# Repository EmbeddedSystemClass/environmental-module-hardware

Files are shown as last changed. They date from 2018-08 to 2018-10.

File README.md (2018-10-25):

irnas_logo
# enviromental-module-hardware

Enviromental module is adafruit feather compatible pinout hardware module. It has Murata Lora module on board, which is used for loraWan communication. It integrates a MCP25625 CAN controller with integrated Tranciver.

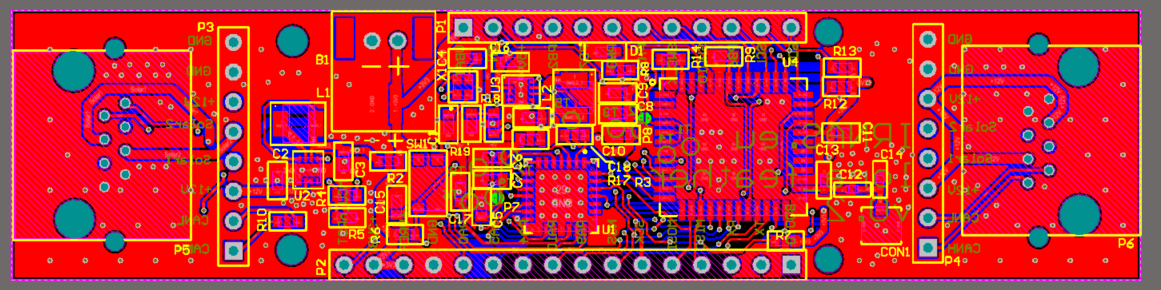
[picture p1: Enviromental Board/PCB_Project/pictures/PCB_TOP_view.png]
enviromental-PCB

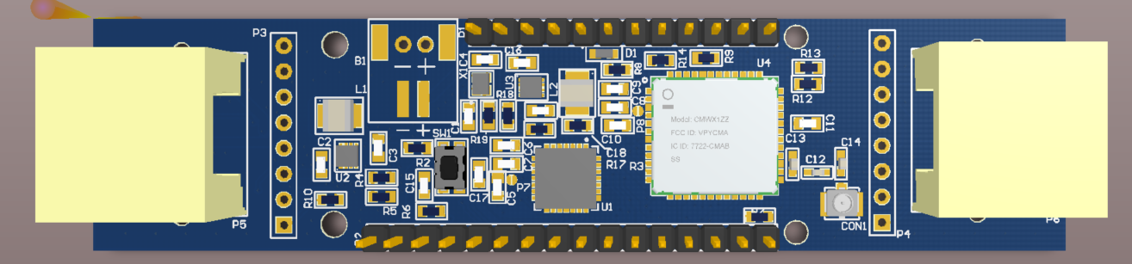
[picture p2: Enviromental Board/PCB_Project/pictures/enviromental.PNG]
enviromental-3D


## Connectors pinout 

* PIN1 - +3V3/VBAT
* PIN2 - EN
* PIN3 - +5V
* PIN4 - PB2
* PIN5 - PB7
* PIN6 - PH0
* PIN7 - PH1
* PIN8 - SWCLK
* PIN9 - SWDIO
* PIN10 - PB6
* PIN11 - SCL
* PIN12 - SDA
* PIN13 - BOOT0
* PIN14 - TX
* PIN15 - RX
* PIN16 - MISO
* PIN17 - MOSI
* PIN18 - SCK
* PIN19 - NSS
* PIN20 - PA9
* PIN21 - PA10
* PIN22 - PA4
* PIN23 - PA5
* PIN24 - PA0
* PIN25 - GND
* PIN26 - +VREF
* PIN27 - +3V3
* PIN28 - MCU_nRST

Besides this pins, on board there are also ethernet connectors, modified for special use case scenario. It provides the board with +12V input voltage, Can bus, and Solar connection.

block-diagram-envinromental
#### License

All our projects are as usefully open-source as possible.

Hardware including documentation is licensed under [CERN OHL v.1.2. license](http://www.ohwr.org/licenses/cern-ohl/v1.2)

Firmware and software originating from the project is licensed under [GNU GENERAL PUBLIC LICENSE v3](http://www.gnu.org/licenses/gpl-3.0.en.html).

Open data generated by our projects is licensed under [CC0](https://creativecommons.org/publicdomain/zero/1.0/legalcode).

All our websites and additional documentation are licensed under [Creative Commons Attribution-ShareAlike 4 .0 Unported License](https://creativecommons.org/licenses/by-sa/4.0/legalcode).

What this means is that you can use hardware, firmware, software and documentation without paying a royalty and knowing that you'll be able to use your version forever. You are also free to make changes but if you share these changes then you have to do so on the same conditions that you enjoy.

Koruza, GoodEnoughCNC and IRNAS are all names and marks of Institut IRNAS Rače. 
You may use these names and terms only to attribute the appropriate entity as required by the Open Licences referred to above. You may not use them in any other way and in particular you may not use them to imply endorsement or authorization of any hardware that you design, make or sell.

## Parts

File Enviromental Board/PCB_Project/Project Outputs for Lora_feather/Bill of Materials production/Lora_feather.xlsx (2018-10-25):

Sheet: Part List Report
 | Component list |  |  | <Parameter ProjectTitle not found>
 | Source Data From: | Lora_feather.PcbDoc |  |  | Contact:
 | Project: | Lora_feather.PrjPcb
 | Variant: | None |  |  |  |  |  |  | IRNAS
 | Report Date: | 09/10/2018 | 3:30:58 PM |  |  |  |  |  | www.irnas.eu
 | Print Date: | 2018-09-11 | 10:51:26
# | Manufacturer Part Number 1 | Manufacturer 1 | Description | Footprint | Designator | Quantity | Supplier 1 | Supplier Part Number 1 | Supplier Order Qty 1 | Supplier Stock 1 | Supplier Unit Price 1 | Supplier Subtotal 1 | Supplier Currency 1
1 | CRCW06030000Z0EA (https://octopart-clicks.com/click/altium?sku=2122112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) | Vishay (https://octopart-clicks.com/click/altium?sku=2122112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) | RES SMD 0.0OHM JUMPER 1/10W 0603 | 0603RES | R2, R3, R14, R17 | 4 | Farnell | 1711553 (https://octopart-clicks.com/click/altium?sku=2122112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) | 280 | 25000 | 0.01 |  | EUR
2 | CRCW0603120RFKEA (https://octopart-clicks.com/click/altium?sku=1652832RL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) | Vishay (https://octopart-clicks.com/click/altium?sku=1652832RL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) | RES SMD 120 OHM 1% 1/10W 0603 | 0603RES | R10 | 1 | Farnell | 1738892 (https://octopart-clicks.com/click/altium?sku=1652832RL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) | 150 | 7795 | 0.01 | 1.68 | GBP
3 | CRCW0603210KFKEA (https://octopart-clicks.com/click/altium?sku=2138527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) | Vishay (https://octopart-clicks.com/click/altium?sku=2138527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) | Thick Film Resistors - SMD 1/10watt 210Kohms 1% | 0603RES | R19 | 1 | Farnell | 2138527 (https://octopart-clicks.com/click/altium?sku=2138527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) | 70 | 16975 | 0.02 | 1.46 | EUR
4 | TPS62125DSGR (https://octopart-clicks.com/click/altium?sku=2769414RL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) | Texas Instruments (https://octopart-clicks.com/click/altium?sku=2769414RL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) | Voltage Regulators - Switching Regulators 3V-17V, 300mA Buck Converter | WSON-VOLTAGE REGULATOR | U2, U3 | 2 | Farnell | 2769414 (https://octopart-clicks.com/click/altium?sku=2769414RL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) | 140 | 2148 | 0.81 | 112.70 | GBP
5 | CPF0603F10KC1 (https://octopart-clicks.com/click/altium?sku=1527581RL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) | TE Connectivity Neohm (https://octopart-clicks.com/click/altium?sku=1527581RL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) | TE CONNECTIVITY / NEOHM CPF0603F10KC1 SMD Chip Resistor, Thin Film, 10 kohm, 50 V, 0603 [1608 Metric], 63 mW, 1%, CPF Series | 0603RES | R6, R7, R9, R12, R13 | 5 | Farnell | 1527581 (https://octopart-clicks.com/click/altium?sku=1527581RL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) | 350 | 0 | 0.04 | 15.51 | GBP
6 | CRGH0603F1K0 (https://octopart-clicks.com/click/altium?sku=2332003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) | TE Connectivity (https://octopart-clicks.com/click/altium?sku=2332003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) | Thick Film Resistors - SMD CRGH0603 1% 1K0 0.2W | 0603RES | R8 | 1 | Farnell | 2332003 (https://octopart-clicks.com/click/altium?sku=2332003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) | 70 | 0 | 0.01 | 0.98 | GBP
7 | C1608X5R1E105K080AC (https://octopart-clicks.com/click/altium?sku=2346891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) | TDK (https://octopart-clicks.com/click/altium?sku=2346891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) | 1µF 50V Ceramic Capacitor X5R 0603 (1608 Metric) 0.063" L x 0.031" W (1.60mm x 0.80mm) | 0603CAP | C9, C11 | 2 | Farnell | 2346901 (https://octopart-clicks.com/click/altium?sku=2346891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) | 140 | 0 | 0.04 | 6.29 | GBP
8 | VLF302515MT-150M (https://octopart-clicks.com/click/altium?sku=2455319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) | TDK (https://octopart-clicks.com/click/altium?sku=2455319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) | Fixed Inductors 15uH 0.28ohms 0.56A | INDUCTOR 3.0X2.5 | L1 | 1 | Farnell | 2455319 (https://octopart-clicks.com/click/altium?sku=2455319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) | 70 | 867 | 0.90 | 63.07 | EUR
9 | ERJ-3EKF5763V (https://octopart-clicks.com/click/altium?sku=2303298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) | Panasonic (https://octopart-clicks.com/click/altium?sku=2303298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) | Res Thick Film 0603 576K Ohm 1% 0.1W(1/10W) ±100ppm/C Molded SMD Automotive Punched T/R | 0603RES | R5 | 1 | Farnell | 2303298 (https://octopart-clicks.com/click/altium?sku=2303298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) | 100 | 39505 | 0.03 | 2.58 | EUR
10 | ZRB18AR60J226ME01L (https://octopart-clicks.com/click/altium?sku=2469395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) | Murata (https://octopart-clicks.com/click/altium?sku=2469395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) | MURATA ZRB18AR60J226ME01L SMD Multilayer Ceramic Capacitor, 0603 [1608 Metric], 22 F, 6.3 V, 20%, X5R, ZRA Series | 0603Cap | C18 | 1 | Farnell | 2469395 (https://octopart-clicks.com/click/altium?sku=2469395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) | 70 | 8647 | 0.24 | 17.08 | EUR
11 | ZRB18AR61E106ME01L (https://octopart-clicks.com/click/altium?sku=2469398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) | Murata (https://octopart-clicks.com/click/altium?sku=2469398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) | MURATA ZRB18AR61E106ME01L SMD Multilayer Ceramic Capacitor, 0603 [1608 Metric], 10 F, 25 V, 20%, X5R, ZRA Series | 0603CAP | C2, C3, C5, C8, C16, C17 | 6 | Farnell | 2469398 (https://octopart-clicks.com/click/altium?sku=2469398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) | 420 | 12814 | 0.12 | 61.00 | GBP
12 | MCHVR03FTFX1104 (https://octopart-clicks.com/click/altium?sku=2823300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) | Multicomp (https://octopart-clicks.com/click/altium?sku=2823300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) |  | 0603RES | R18 | 1 | Farnell | 2059681 (https://octopart-clicks.com/click/altium?sku=2823300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) | 70 | 10000 | 0.01 | 55.00 | GBP
13 | MCHVR03FTFX1804 (https://octopart-clicks.com/click/altium?sku=2825653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) | Multicomp (https://octopart-clicks.com/click/altium?sku=2825653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) |  | 0603RES | R4 | 1 | Farnell | 2825653 (https://octopart-clicks.com/click/altium?sku=2825653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) | 70 | 4440 | 0.04 | 2.49 | GBP
14 | MC0402B101K500CT (https://octopart-clicks.com/click/altium?sku=1758968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) | Multicomp (https://octopart-clicks.com/click/altium?sku=1758968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) | MULTICOMP MC0402B101K500CT SMD Multilayer Ceramic Capacitor, MC Series, 100 pF, 10%, X7R, 50 V, 0402 [1005 Metric] | 0402CAP | C12 | 1 | Farnell | 3019226 (https://octopart-clicks.com/click/altium?sku=1758968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) | 70 | 0 | 0.02 | 1.13 | GBP
15 | 44620-0001 (https://octopart-clicks.com/click/altium?sku=2782009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) | Molex (https://octopart-clicks.com/click/altium?sku=2782009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) | MODULAR JACK | ETHERNET CONN | P5, P6 | 2 | Farnell | 2782009 (https://octopart-clicks.com/click/altium?sku=2782009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) | 140 | 1091 | 0.67 | 93.80 | EUR
16 | MCP25625-E/ML (https://octopart-clicks.com/click/altium?sku=2448754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) | Microchip (https://octopart-clicks.com/click/altium?sku=2448754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) | MICROCHIP MCP25625-E/ML CAN Bus, Controller with Transceiver, CAN, SPI, 3, 2, 2.7 V, 5.5 V, QFN | MCP25625 | U1 | 1 | Farnell | 2448754 (https://octopart-clicks.com/click/altium?sku=2448754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) | 70 | 53 | 1.87 | 130.90 | EUR | avnet | MCP25625-E/ML
17 | 06035C100KAT2A (https://octopart-clicks.com/click/altium?sku=2665201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) | Kyocera AVX (https://octopart-clicks.com/click/altium?sku=2665201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) | Cap Ceramic 10pF 50V X7R 10% SMD 0603 125C T/R | 0603CAP | C1, C4 | 2 | Farnell | 2332633 (https://octopart-clicks.com/click/altium?sku=2665201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) | 140 | 0 | 0.02 | 91.60 | GBP
18 | KPG1-1608VGC-TT-5MAV (https://octopart-clicks.com/click/altium?sku=2671383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) | Kingbright (https://octopart-clicks.com/click/altium?sku=2671383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) |  | LED | D1 | 1 | Farnell | 2671383 (https://octopart-clicks.com/click/altium?sku=2671383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) | 70 | 3905 | 0.54 | 37.94 | EUR
19 | C0603C104K4RAC7081 (https://octopart-clicks.com/click/altium?sku=2522597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) | KEMET (https://octopart-clicks.com/click/altium?sku=2522597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) | Multilayer Ceramic Capacitors MLCC - SMD/SMT .1uF 50Volts X7R +/-10% 0603 STD | 0603CAP | C6, C7, C10, C15 | 4 | Farnell | 1414027 (https://octopart-clicks.com/click/altium?sku=2522597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) | 280 | 0 | 0.03 | 9.38 | GBP
20 | LFXTAL059585 (https://octopart-clicks.com/click/altium?sku=2627212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) | IQD (https://octopart-clicks.com/click/altium?sku=2627212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) | IQD FREQUENCY PRODUCTS LFXTAL059585 CRYSTAL, 20MHZ, 10PF, 2MM X 1.6MM New | IQXC-42 | X1 | 1 | Farnell | 1923-1593-1-ND (https://octopart-clicks.com/click/altium?sku=2627212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) | 70 | 57 | 0.69 | 48.09 | EUR
21 | U.FL-R-SMT-1(10) (https://octopart-clicks.com/click/altium?sku=1688077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) | Hirose (https://octopart-clicks.com/click/altium?sku=1688077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) | CONN UMC JACK STR 50 OHM SMD | UFL SMD CONNECTOR | CON1 | 1 | Farnell | 1688077 (https://octopart-clicks.com/click/altium?sku=1688077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) | 70 | 52313 | 0.49 | 34.30 | GBP
22 | LPS3314-103MRB (https://octopart-clicks.com/click/altium?sku=2408046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) | Coilcraft (https://octopart-clicks.com/click/altium?sku=2408046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) | COILCRAFT LPS3314-103MRB INDUCTOR, SHLD, 10UH, 20%, 0.65A, SMD | INDUCTOR 3.0X2.5 | L2 | 1 | Mouser | 994-LPS3314-103MRB (https://octopart-clicks.com/click/altium?sku=2408046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) | 70 | 62 | 0.89 | 62.44 | EUR
23 |  |  | SWITCH TACTILE SPST-NO 0.05A 32V | TACTILE BUTTON | SW1 | 1 | Farnell | 2845727 | 70
 |  |  |  |  |  | 42 |  |  | 3050 |  |  | 849.42
Approved |  |  |  | Notes
 |  |  |  | pcs: |  | 70 |  | Total |  | 849.42 |  | <none>
 |  |  |  |  |  |  |  | Price for 1pcs |  | 12.13 |  | <none>

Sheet: Project Information
Project Full Path | C:\Users\vojislav\OneDrive\IRNAS-Common\Electronics-Development\Agrelaeco\lora feather_ver0.2\lora feather\PCB_Project\Lora_feather.PrjPcb
Project Filename | Lora_feather.PrjPcb
Variant Name | None
Data-Source Filename | Lora_feather.PcbDoc
Data-Source Full Path | C:\Users\vojislav\OneDrive\IRNAS-Common\Electronics-Development\Agrelaeco\lora feather_ver0.2\lora feather\PCB_Project\Lora_feather.PcbDoc
Title | Bill of Materials production For PCB Document [Lora_feather.PcbDoc]
Total Quantity | 61
Report Time | 3:30:58 PM
Report Date | 09/10/2018
Report Date & Tine | 09/10/2018 3:30:58 PM
Output Name | Bill of Materials production
Output Type | BOM_PartType
Output Generator Name | BOM
Output Generator Description | Bill of Materials

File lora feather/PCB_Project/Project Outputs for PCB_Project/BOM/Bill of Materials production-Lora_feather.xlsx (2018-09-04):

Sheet: Part List Report
 | Component list |  |  | <Parameter ProjectTitle not found>
 | Source Data From: | Lora_feather.PcbDoc |  |  | Contact:
 | Project: | PCB_Project.PrjPcb
 | Variant: | None |  |  |  |  |  |  | IRNAS
 | Report Date: | 8/27/2018 | 12:04:45 PM |  |  |  |  |  | www.irnas.eu
 | Print Date: | 2018-08-27 | 12:04:54
# | Manufacturer Part Number 1 | Manufacturer 1 | Description | Footprint | #Column Name Error:Category | Quantity | Supplier 1 | Supplier Part Number 1 | Supplier Order Qty 1 | Supplier Stock 1 | Supplier Unit Price 1 | Supplier Subtotal 1 | Supplier Currency 1
1 | CRCW06030000Z0EA (https://octopart-clicks.com/click/altium?sku=2122112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) | Vishay (https://octopart-clicks.com/click/altium?sku=2122112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) | RES SMD 0.0OHM JUMPER 1/10W 0603 | 0603RES |  | 6 | Farnell | 2122112 (https://octopart-clicks.com/click/altium?sku=2122112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) |  | 0 |  |  | Loading...
2 | CRCW0603120RFKEA (https://octopart-clicks.com/click/altium?sku=1652832RL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) | Vishay (https://octopart-clicks.com/click/altium?sku=1652832RL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) | RES SMD 120 OHM 1% 1/10W 0603 | 0603RES |  | 1 | Farnell | 1652832RL (https://octopart-clicks.com/click/altium?sku=1652832RL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) |  | 0 |  |  | Loading...
3 | CRCW0603210KFKEA (https://octopart-clicks.com/click/altium?sku=2138527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) | Vishay (https://octopart-clicks.com/click/altium?sku=2138527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) | Thick Film Resistors - SMD 1/10watt 210Kohms 1% | 0603Res |  | 1 | Farnell | 2138527 (https://octopart-clicks.com/click/altium?sku=2138527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) | 10 | 17135 | 0.03 | 0.28 | EUR
4 | TPS62125DSGR (https://octopart-clicks.com/click/altium?sku=2769414RL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) | Texas Instruments (https://octopart-clicks.com/click/altium?sku=2769414RL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) | Voltage Regulators - Switching Regulators 3V-17V, 300mA Buck Converter | WSON-VOLTAGE REGULATOR |  | 2 | Farnell | 2769414RL (https://octopart-clicks.com/click/altium?sku=2769414RL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) |  | 0 |  |  | Loading...
5 | CPF0603F10KC1 (https://octopart-clicks.com/click/altium?sku=1527581RL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) | TE Connectivity Neohm (https://octopart-clicks.com/click/altium?sku=1527581RL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) | TE CONNECTIVITY / NEOHM CPF0603F10KC1 SMD Chip Resistor, Thin Film, 10 kohm, 50 V, 0603 [1608 Metric], 63 mW, 1%, CPF Series | 0603RES |  | 5 | Farnell | 1527581RL (https://octopart-clicks.com/click/altium?sku=1527581RL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) |  | 0 |  |  | Loading...
6 | CRGH0603F1K0 (https://octopart-clicks.com/click/altium?sku=2332003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) | TE Connectivity (https://octopart-clicks.com/click/altium?sku=2332003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) | Thick Film Resistors - SMD CRGH0603 1% 1K0 0.2W | 0603Res |  | 1 | Farnell | 2332003 (https://octopart-clicks.com/click/altium?sku=2332003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) | 10 | 129 | 0.02 | 0.16 | EUR
7 | VLF302515MT-150M (https://octopart-clicks.com/click/altium?sku=2455319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) | TDK (https://octopart-clicks.com/click/altium?sku=2455319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) | Fixed Inductors 15uH 0.28ohms 0.56A | INDUCTOR 3.0X2.5 |  | 1 | Farnell | 2455319 (https://octopart-clicks.com/click/altium?sku=2455319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) | 5 | 942 | 1.38 | 6.90 | EUR
8 | UMK107B7104KAHT (https://octopart-clicks.com/click/altium?sku=963-UMK107B7104KAHT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) | Taiyo Yuden (https://octopart-clicks.com/click/altium?sku=963-UMK107B7104KAHT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) | Multilayer Ceramic Capacitors MLCC - SMD/SMT .1uF 50Volts X7R +/-10% 0603 STD | 0603CAP |  | 4 | Mouser | 963-UMK107B7104KAHT (https://octopart-clicks.com/click/altium?sku=963-UMK107B7104KAHT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) | 12 | 0 | 0.05 | 0.65 | USD
9 | Supplier disabled (https://octopart-clicks.com/click/altium?manufacturer=Supplier%20disabled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) | Supplier disabled (https://octopart-clicks.com/click/altium?manufacturer=Supplier%20disabled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) | SWITCH TACTILE SPST-NO 0.05A 32V | TACTILE BUTTON |  | 1 | C&K Components | 2845727 (https://octopart-clicks.com/click/altium?manufacturer=Supplier%20disabled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) |  |  |  |  | Supplier disabled
10 | ERJ-3EKF5763V (https://octopart-clicks.com/click/altium?sku=2303298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) | Panasonic (https://octopart-clicks.com/click/altium?sku=2303298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) | Res Thick Film 0603 576K Ohm 1% 0.1W(1/10W) ±100ppm/C Molded SMD Automotive Punched T/R | 0603RES |  | 1 | Farnell | 2303298 (https://octopart-clicks.com/click/altium?sku=2303298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) | 10 | 39605 | 0.04 | 0.42 | EUR
11 | GRT188R61H105KE13D (https://octopart-clicks.com/click/altium?sku=81-GRT188R61H105KE3D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) | Murata (https://octopart-clicks.com/click/altium?sku=81-GRT188R61H105KE3D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) | 1µF 50V Ceramic Capacitor X5R 0603 (1608 Metric) 0.063" L x 0.031" W (1.60mm x 0.80mm) | 0603CAP |  | 2 | Mouser | 81-GRT188R61H105KE3D (https://octopart-clicks.com/click/altium?sku=81-GRT188R61H105KE3D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) | 6 | 0 | 0.28 | 1.68 | USD
12 | ZRB18AR60J226ME01L (https://octopart-clicks.com/click/altium?sku=2666613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) | Murata (https://octopart-clicks.com/click/altium?sku=2666613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) | MURATA ZRB18AR60J226ME01L SMD Multilayer Ceramic Capacitor, 0603 [1608 Metric], 22 F, 6.3 V, 20%, X5R, ZRA Series | 0603Cap |  | 1 | Farnell | 2666613 (https://octopart-clicks.com/click/altium?sku=2666613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) | 3000 | 27000 | 0.09 | 275.40 | EUR
13 | ZRB18AR61E106ME01L (https://octopart-clicks.com/click/altium?sku=2666614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) | Murata (https://octopart-clicks.com/click/altium?sku=2666614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) | MURATA ZRB18AR61E106ME01L SMD Multilayer Ceramic Capacitor, 0603 [1608 Metric], 10 F, 25 V, 20%, X5R, ZRA Series | 0603CAP |  | 6 | Farnell | 2666614 (https://octopart-clicks.com/click/altium?sku=2666614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) |  | 0 |  |  | Loading...
14 | MCHVR03FTFX1104 (https://octopart-clicks.com/click/altium?sku=2823300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) | Multicomp (https://octopart-clicks.com/click/altium?sku=2823300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) |  | 0603Res |  | 1 | Farnell | 2823300 (https://octopart-clicks.com/click/altium?sku=2823300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) |  | 0 |  |  | Loading...
15 | MCHVR03FTFX1804 (https://octopart-clicks.com/click/altium?sku=2825653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) | Multicomp (https://octopart-clicks.com/click/altium?sku=2825653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) |  | 0603RES |  | 1 | Farnell | 2825653 (https://octopart-clicks.com/click/altium?sku=2825653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) |  | 0 |  |  | Loading...
16 | MC0402B101K500CT (https://octopart-clicks.com/click/altium?sku=1758968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) | Multicomp (https://octopart-clicks.com/click/altium?sku=1758968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) | MULTICOMP MC0402B101K500CT SMD Multilayer Ceramic Capacitor, MC Series, 100 pF, 10%, X7R, 50 V, 0402 [1005 Metric] | 0402CAP |  | 1 | Farnell | 1758968 (https://octopart-clicks.com/click/altium?sku=1758968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) |  | 0 |  |  | Loading...
17 | 44620-0001 (https://octopart-clicks.com/click/altium?sku=2782009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) | Molex (https://octopart-clicks.com/click/altium?sku=2782009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) | MODULAR JACK | ETHERNET CONN |  | 2 | Farnell | 2782009 (https://octopart-clicks.com/click/altium?sku=2782009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) | 6 | 1116 | 0.69 | 4.13 | EUR
18 | MCP25625-E/ML (https://octopart-clicks.com/click/altium?sku=2448754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) | Microchip (https://octopart-clicks.com/click/altium?sku=2448754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) | MICROCHIP MCP25625-E/ML CAN Bus, Controller with Transceiver, CAN, SPI, 3, 2, 2.7 V, 5.5 V, QFN | MCP25625 |  | 1 | Farnell | 2448754 (https://octopart-clicks.com/click/altium?sku=2448754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) | 3 | 69 | 2.28 | 6.84 | EUR
19 | 06035C100KAT2A (https://octopart-clicks.com/click/altium?sku=2665201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) | Kyocera AVX (https://octopart-clicks.com/click/altium?sku=2665201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) | Cap Ceramic 10pF 50V X7R 10% SMD 0603 125C T/R | 0603CAP |  | 2 | Farnell | 2665201 (https://octopart-clicks.com/click/altium?sku=2665201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) |  | 0 |  |  | Loading...
20 | KPG1-1608VGC-TT-5MAV (https://octopart-clicks.com/click/altium?sku=2671383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) | Kingbright (https://octopart-clicks.com/click/altium?sku=2671383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) |  | LED |  | 1 | Farnell | 2671383 (https://octopart-clicks.com/click/altium?sku=2671383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) | 5 | 3935 | 0.58 | 2.90 | EUR
21 | LFXTAL059585 (https://octopart-clicks.com/click/altium?sku=2627212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) | IQD (https://octopart-clicks.com/click/altium?sku=2627212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) | IQD FREQUENCY PRODUCTS LFXTAL059585 CRYSTAL, 20MHZ, 10PF, 2MM X 1.6MM New | IQXC-42 |  | 1 | Farnell | 2627212 (https://octopart-clicks.com/click/altium?sku=2627212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) | 3 | 57 | 0.81 | 2.44 | EUR
22 | U.FL-R-SMT-1(10) (https://octopart-clicks.com/click/altium?sku=1688077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) | Hirose (https://octopart-clicks.com/click/altium?sku=1688077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) | CONN UMC JACK STR 50 OHM SMD | UFL SMD CONNECTOR |  | 1 | Farnell | 1688077 (https://octopart-clicks.com/click/altium?sku=1688077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) |  | 0 |  |  | Loading...
23 | LPS3314-103MRB (https://octopart-clicks.com/click/altium?sku=2408046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) | Coilcraft (https://octopart-clicks.com/click/altium?sku=2408046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) | COILCRAFT LPS3314-103MRB INDUCTOR, SHLD, 10UH, 20%, 0.65A, SMD | INDUCTOR 3.0X2.5 |  | 1 | Farnell | 2408046 (https://octopart-clicks.com/click/altium?sku=2408046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) | 3 | 37 | 0.89 | 2.68 | EUR
24 | 1862 (https://octopart-clicks.com/click/altium?sku=485-1862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) | Adafruit Industries (https://octopart-clicks.com/click/altium?sku=485-1862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) | JST-PH 2-Pin SMT Right Angle Breakout Board | BAT_CON |  | 1 | Mouser | 485-1862 (https://octopart-clicks.com/click/altium?sku=485-1862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) | 3 | 104 | 1.50 | 4.50 | USD
25 |  |  |  | 0402CAP |  | 2
26 |  |  | Header, 12-Pin | HDR1X12 |  | 1
27 |  |  | Header, 16-Pin | HDR1X16 |  | 1
28 |  |  | Header, 8-Pin | HDR1X8 |  | 2
29 |  |  | LRA Module ES0 | LORA MODULE ES0 |  | 1
30 |  |  | Test point | TEST_PAD |  | 9
 |  |  |  |  |  | 61 |  |  | 3076 |  |  | 308.976
Approved |  |  |  | Notes
 |  |  |  | pcs: |  | 3 |  | Total |  | 308.976 |  | <none>
 |  |  |  |  |  |  |  | Price for 1pcs |  | 102.99 |  | <none>

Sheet: Project Information
Project Full Path | C:\Users\CvejaBog\Desktop\praksa\lora feather_ver0.2\lora feather\PCB_Project\PCB_Project.PrjPcb
Project Filename | PCB_Project.PrjPcb
Variant Name | None
Data-Source Filename | Lora_feather.PcbDoc
Data-Source Full Path | C:\Users\CvejaBog\Desktop\praksa\lora feather_ver0.2\lora feather\PCB_Project\Lora_feather.PcbDoc
Title | Bill of Materials production For PCB Document [Lora_feather.PcbDoc]
Total Quantity | 61
Report Time | 12:04:45 PM
Report Date | 8/27/2018
Report Date & Tine | 8/27/2018 12:04:45 PM
Output Name | Bill of Materials production
Output Type | BOM_PartType
Output Generator Name | BOM
Output Generator Description | Bill of Materials

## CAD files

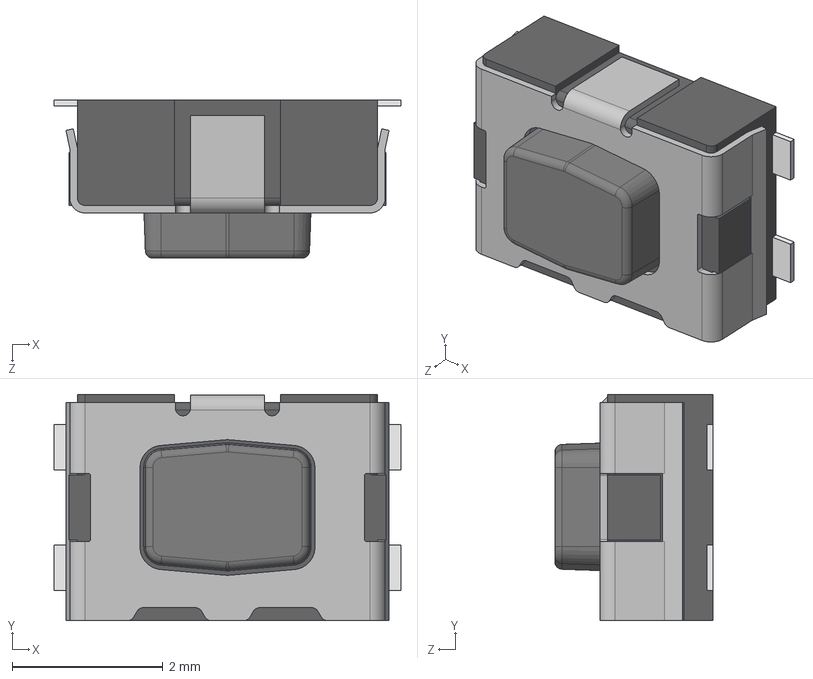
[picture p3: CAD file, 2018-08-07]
Enviromental Board/PCB_Project/step_files/button/3D/User Library-Switch-CK-KMR2.STEP
4.60 x 3.00 x 2.10 mm
User Library-Switch-CK-KMR2_Button
User Library-Switch-CK-KMR2_Boitier
User Library-Switch-CK-KMR2_Tole
User Library-Switch-CK-KMR2_Pads

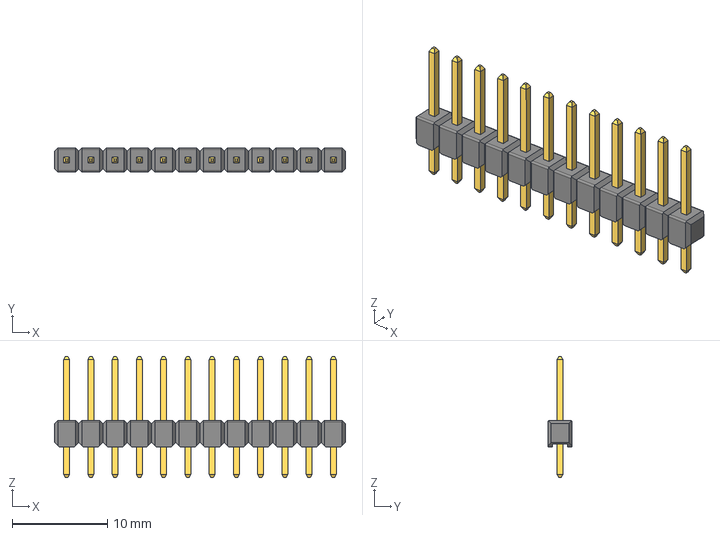
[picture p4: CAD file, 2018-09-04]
Enviromental Board/PCB_Project/step_files/header-12/Pin Header 1x12 TH Pitch 2.54mm.stp
30.5 x 2.54 x 12.7 mm

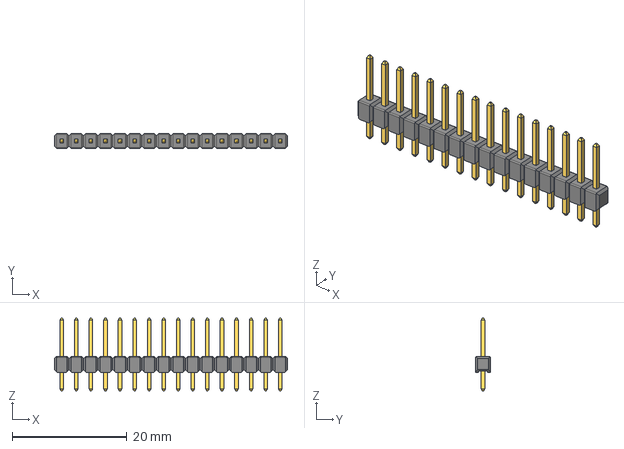
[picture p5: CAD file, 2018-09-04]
Enviromental Board/PCB_Project/step_files/header-16/Pin Header 1x16 TH Pitch 2.54mm.stp
40.6 x 2.54 x 12.7 mm

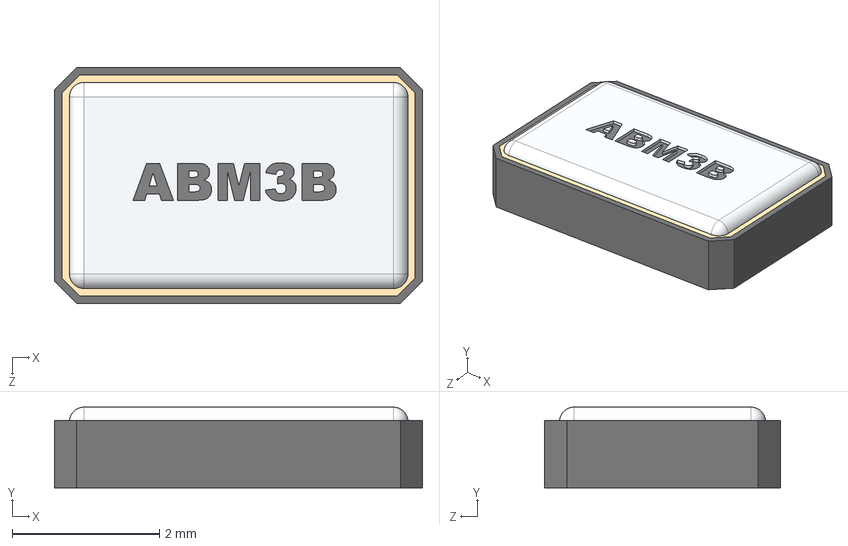
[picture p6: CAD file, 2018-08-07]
Enviromental Board/PCB_Project/step_files/oscilator_3D/User Library-ABM3B.STEP
5.00 x 1.10 x 3.20 mm
User Library-ABM3B_BLOCO_Valor predeterminado
User Library-ABM3B_PIN_2_3_4_Valor predeterminado x 3
User Library-ABM3B_BASE_Valor predeterminado
User Library-ABM3B_PIN_1_Valor predeterminado
User Library-ABM3B_TAMPA_Valor predeterminado

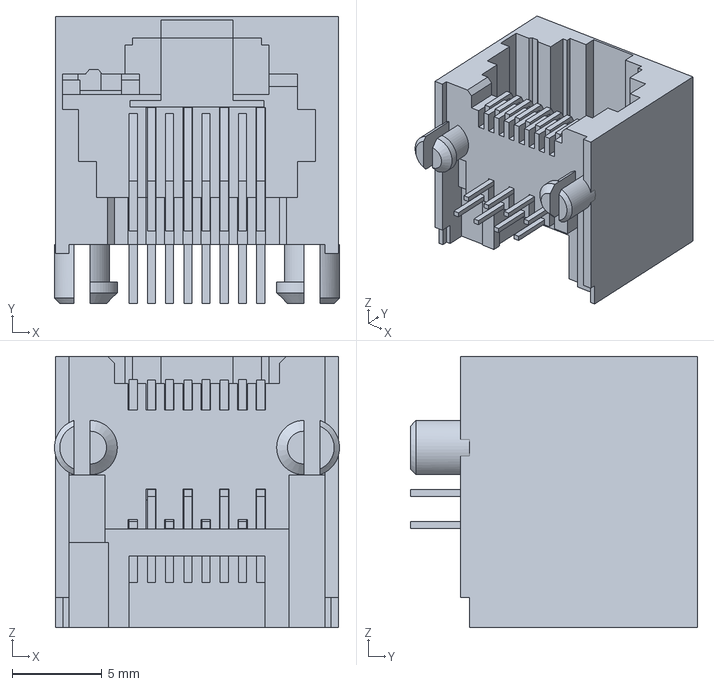
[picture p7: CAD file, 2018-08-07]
Enviromental Board/PCB_Project/step_files/ethernet_connector/3D/446200001.stp
15.9 x 16.0 x 15.1 mm

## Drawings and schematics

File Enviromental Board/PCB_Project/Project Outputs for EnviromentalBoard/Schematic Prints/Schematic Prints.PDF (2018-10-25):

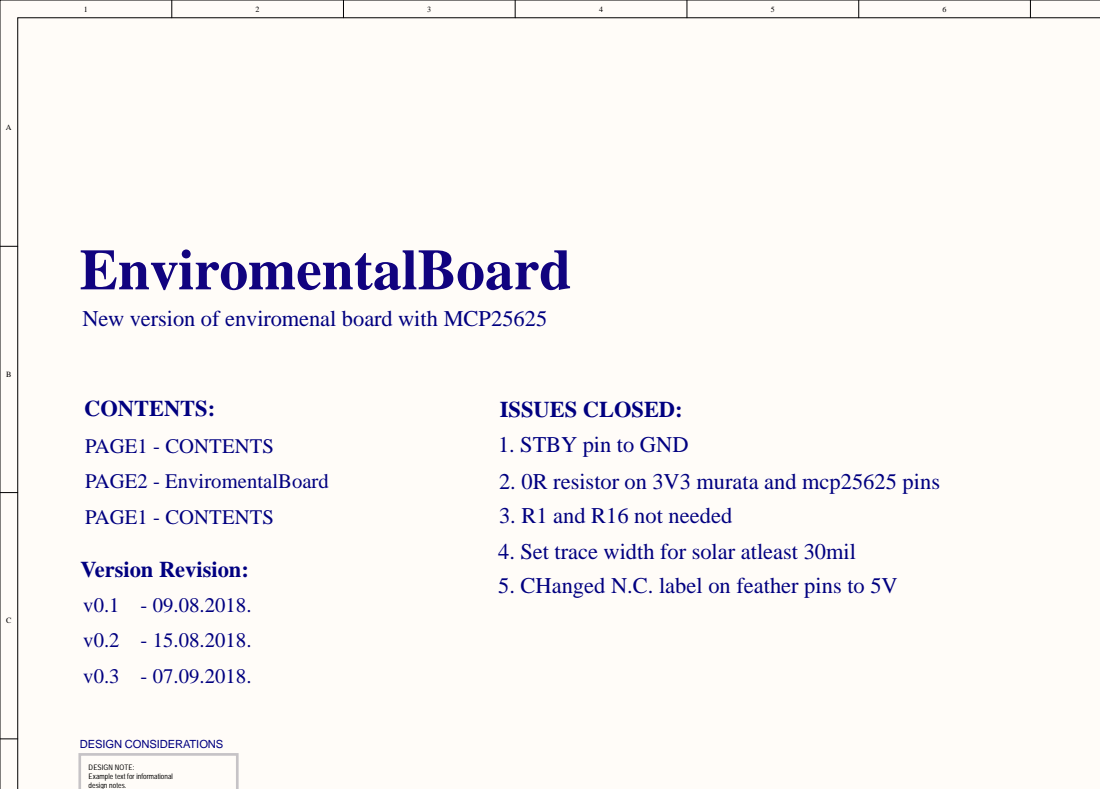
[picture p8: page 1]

New version of enviromenal board with MCP25625

ISSUES CLOSED:
1. STBY pin to GND
2. 0R resistor on 3V3 murata and mcp25625 pins
3. R1 and R16 not needed
4. Set trace width for solar atleast 30mil
5. CHanged N.C. label on feather pins to 5V

DESIGN NOTE:
Example text for informational
design notes.

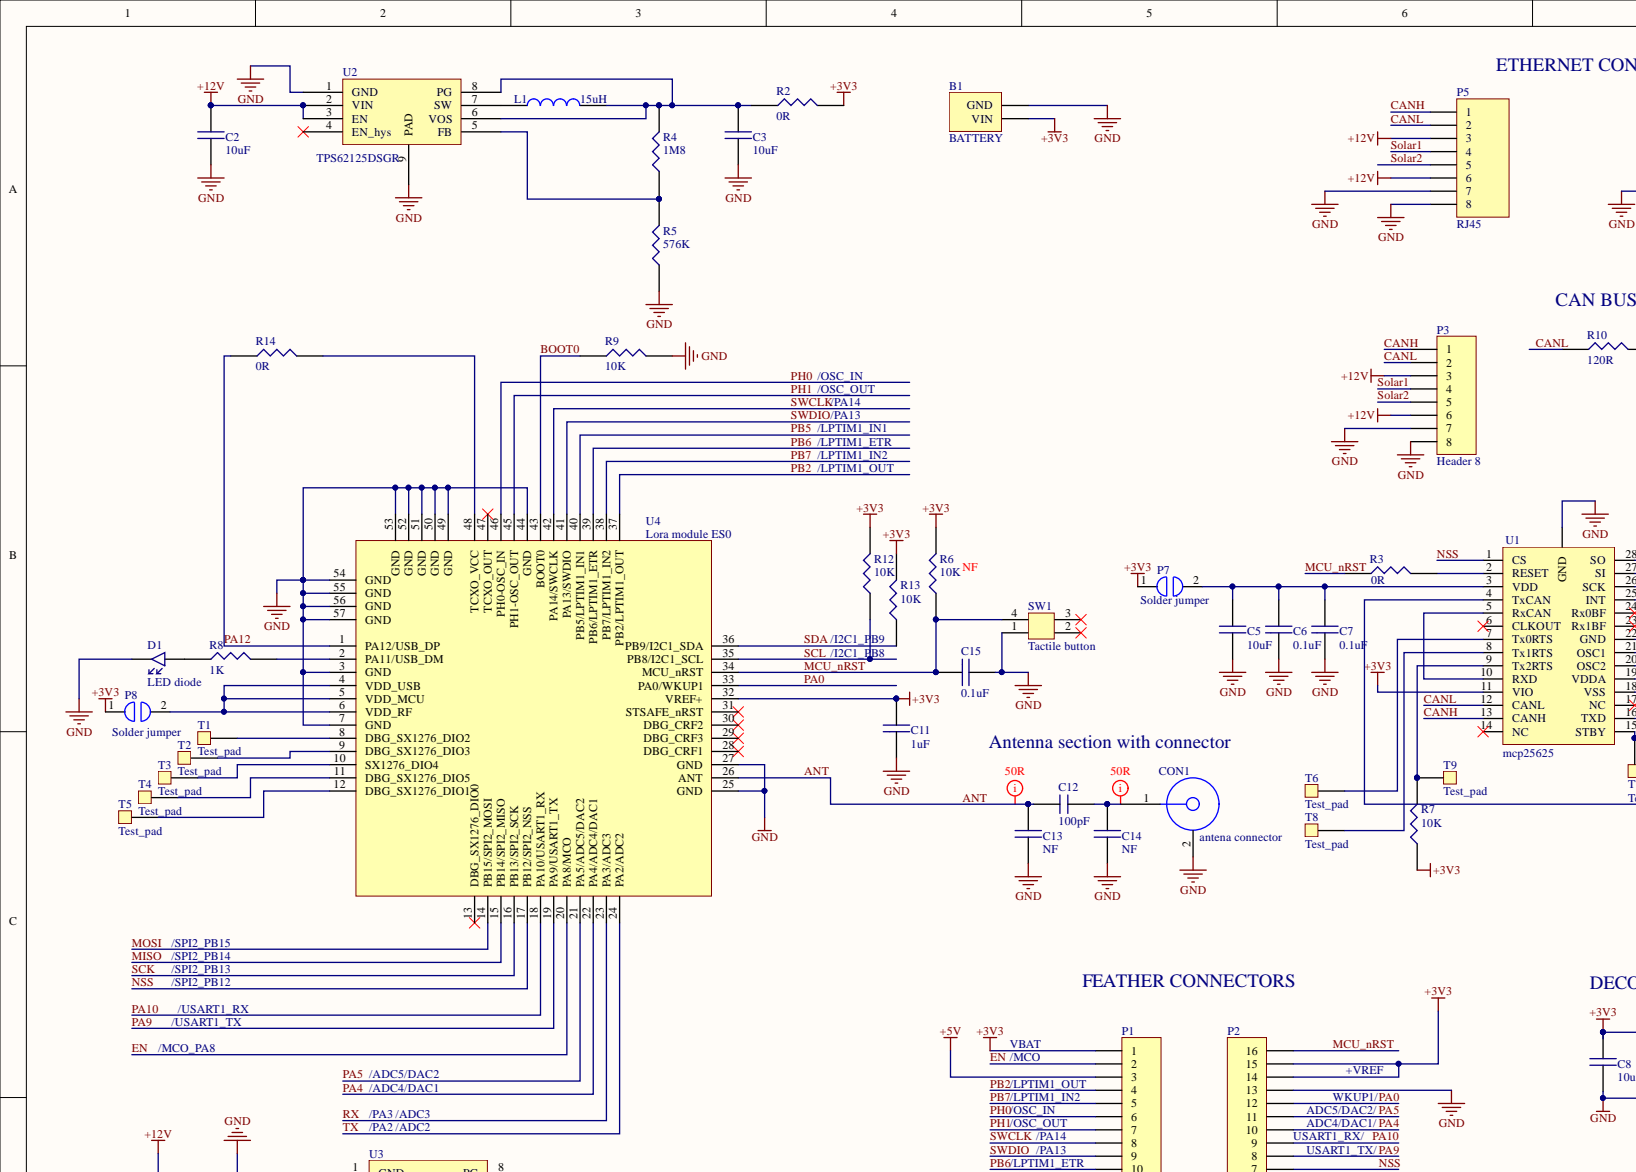
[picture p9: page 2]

PH1 /OSC_OUT
SWCLK /PA14
SWDIO /PA13
PB5 /LPTIM1_IN1

GND 50 GND 51 GND 52 GND 53

U4 Lora module ES0

GND 54
GND 55
GND 56
GND 57

RxCAN 5

PA11/USB_DM 2 | | SCL /I2C1_PB8

Tx2RTS 9
RXD 10

VDD_USB 4 | PA0
VDD_MCU 5

CANL | CANL 12

Antenna section with connector

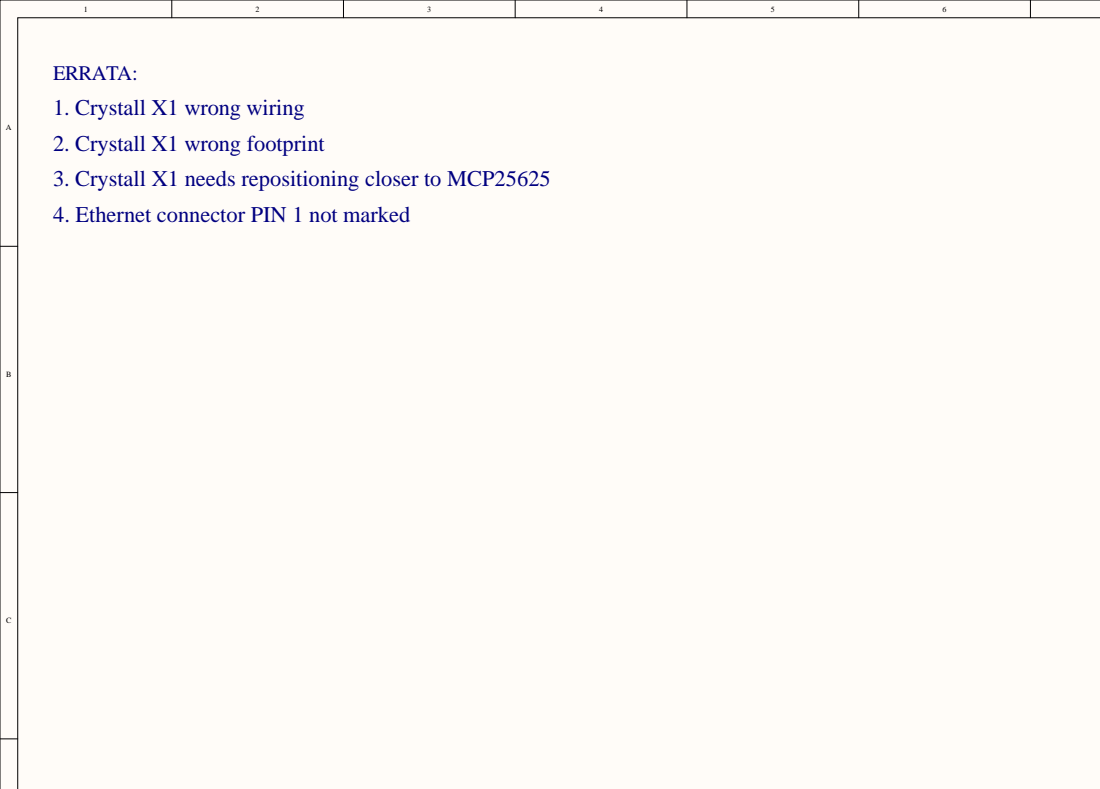
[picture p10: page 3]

ERRATA:
1. Crystall X1 wrong wiring
2. Crystall X1 wrong footprint
3. Crystall X1 needs repositioning closer to MCP25625
4. Ethernet connector PIN 1 not marked

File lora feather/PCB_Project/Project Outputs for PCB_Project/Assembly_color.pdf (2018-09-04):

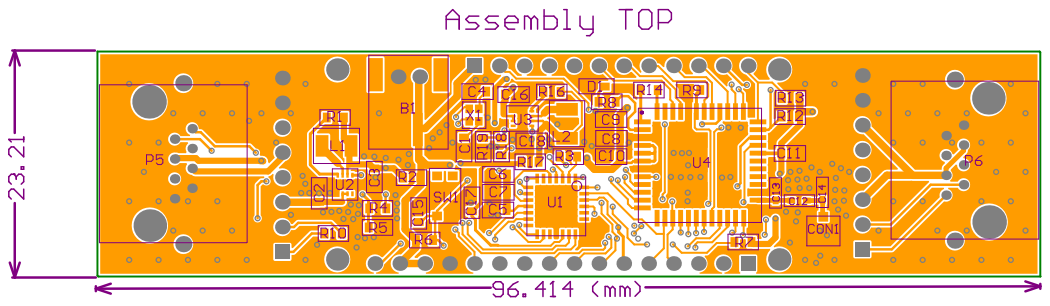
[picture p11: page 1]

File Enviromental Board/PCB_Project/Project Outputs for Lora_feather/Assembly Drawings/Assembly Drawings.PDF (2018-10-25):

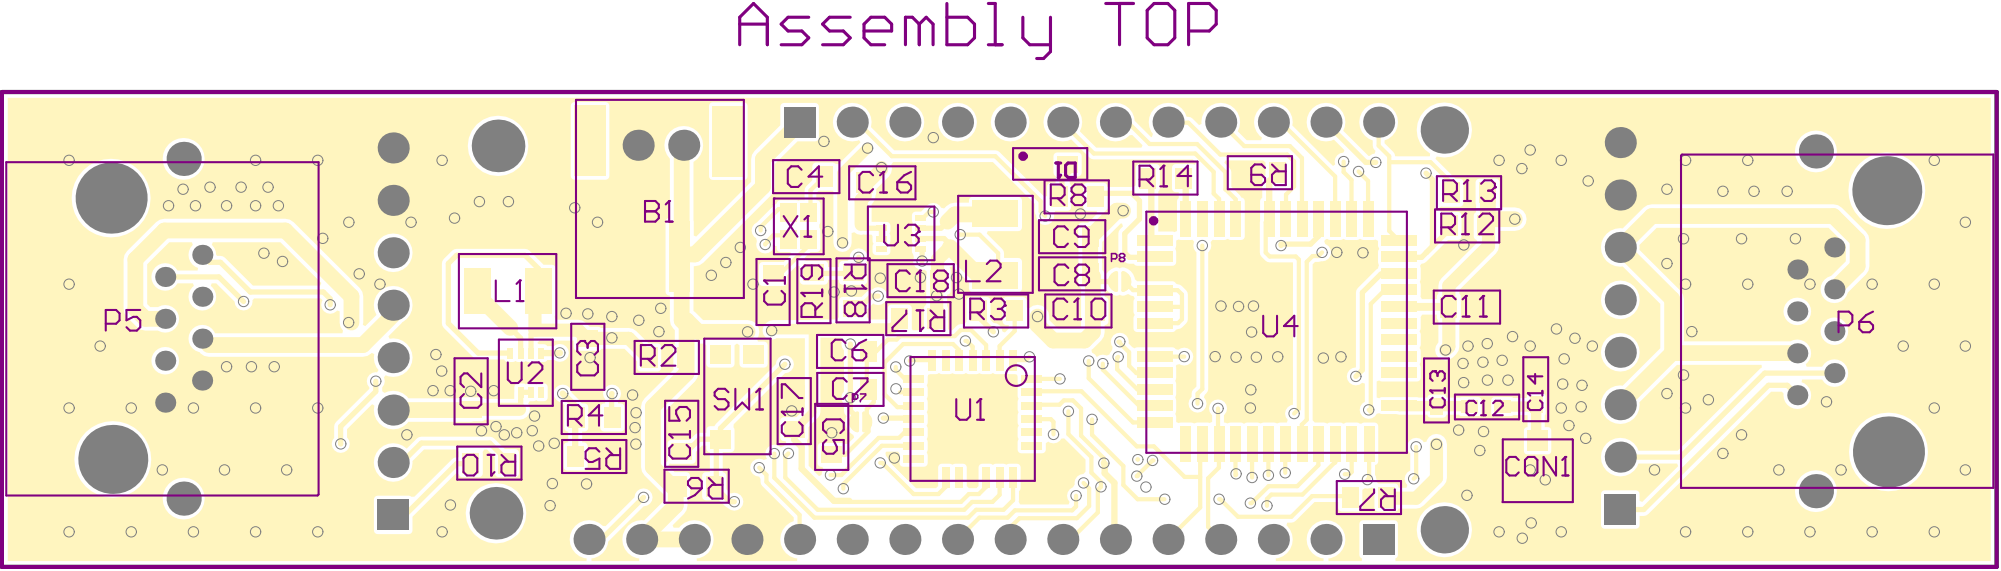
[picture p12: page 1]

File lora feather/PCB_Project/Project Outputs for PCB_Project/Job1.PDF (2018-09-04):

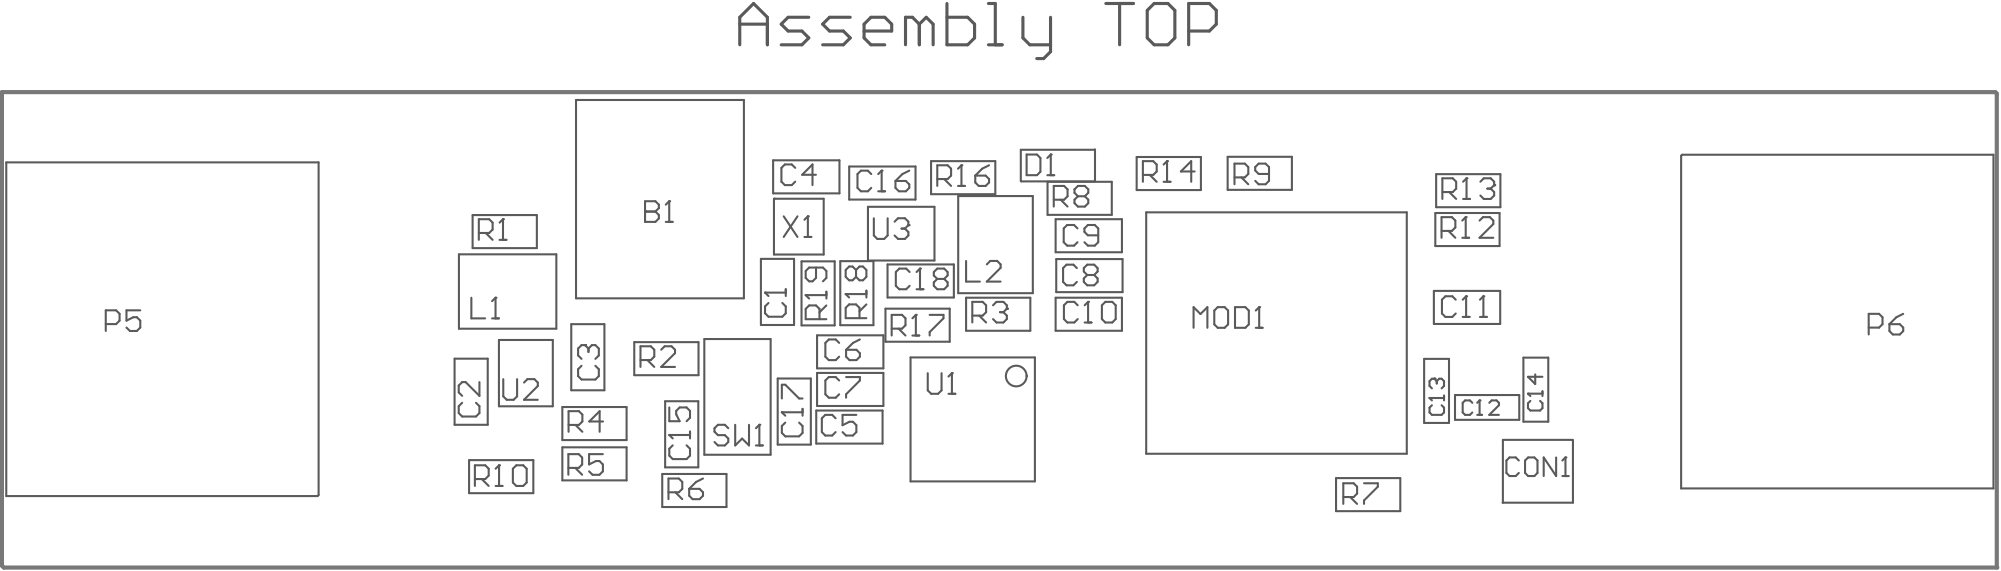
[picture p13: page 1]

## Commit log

2018-08-07 lora files
    [446200001.stp, EDI2CAP.CFG, KMR221NG_LFS.SchLib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]
2018-09-04 New version with MCP25625
    [446200001.stp, Bill of Materials production-Lora_feather.xlsx, Bill of Materials production-PCB_Project.xlsx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]
2018-10-25 v0.3 debbuging
    [446200001.stp, EDI2CAP.CFG, EnviromentalBoard.PcbDoc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]
